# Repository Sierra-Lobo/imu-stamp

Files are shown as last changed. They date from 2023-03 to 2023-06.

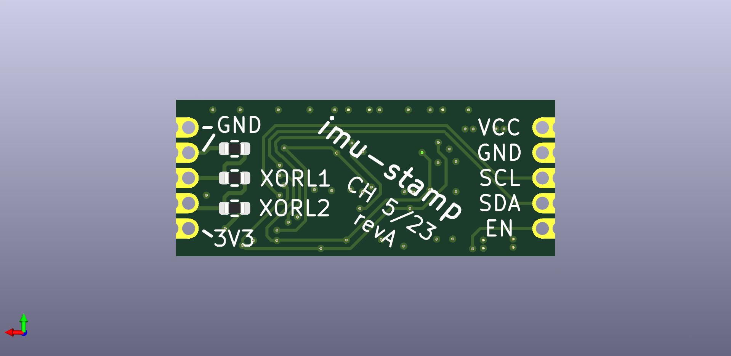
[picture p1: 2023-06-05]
hardware/revA/docs/imu-stamp-3d-bot.jpg

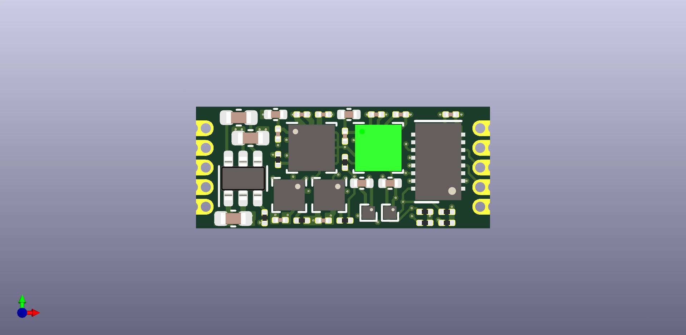
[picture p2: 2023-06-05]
hardware/revA/docs/imu-stamp-3d-top.jpg

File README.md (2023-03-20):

# imu-stamp

9-axis inertial measurement unit with dual sensors for gyro, mag, and accel measurements.

see LTC4317 datasheet for information on setting the I2C addresses of each sensor.

imu-stamp-3d-top

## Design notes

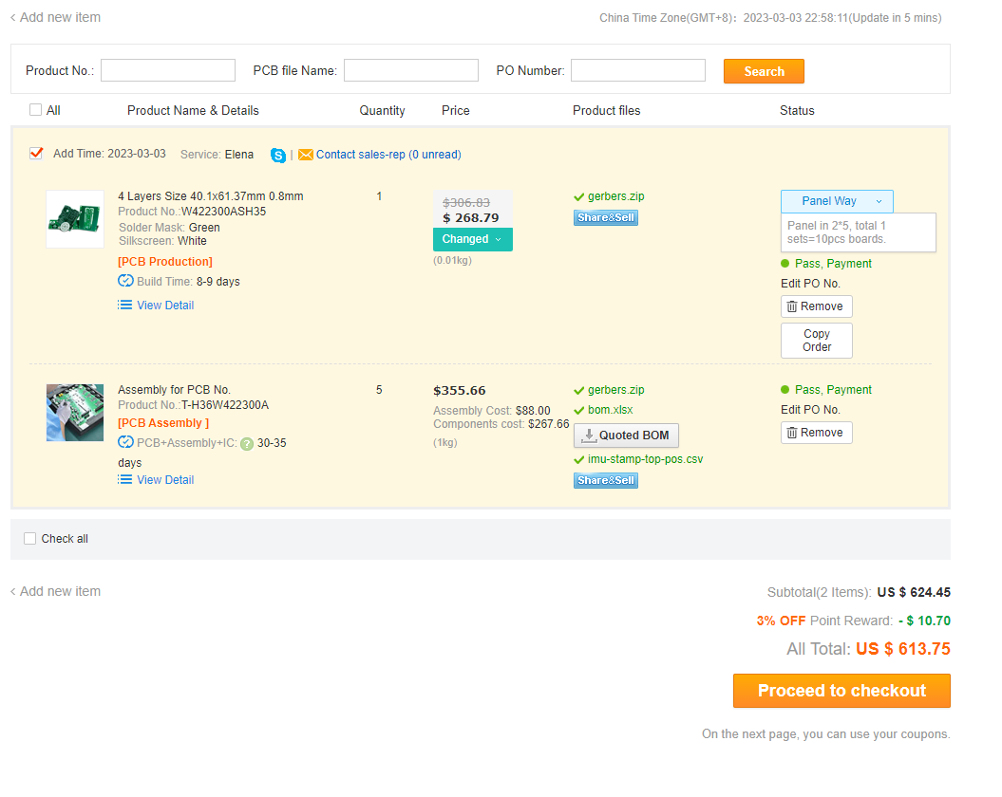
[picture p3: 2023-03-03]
hardware/revA/docs/PCBway-quote-230303.PNG

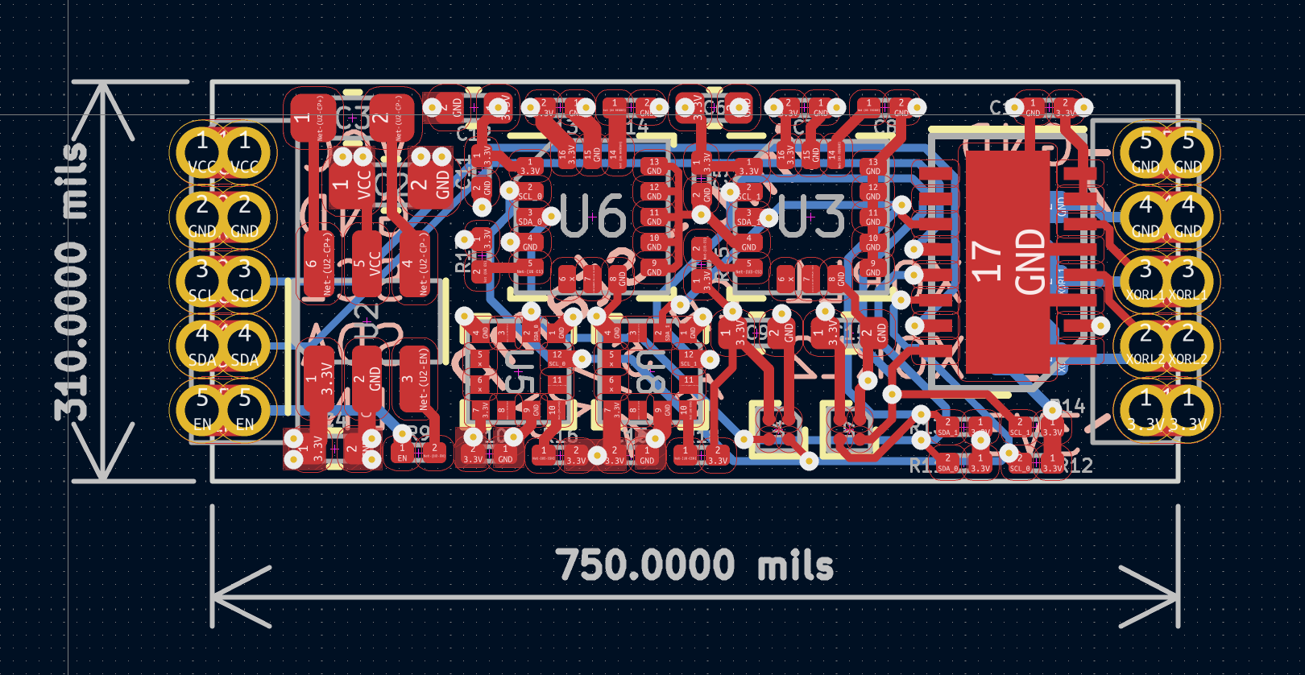
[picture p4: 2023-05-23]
hardware/revA/docs/imu-stamp-2d.PNG

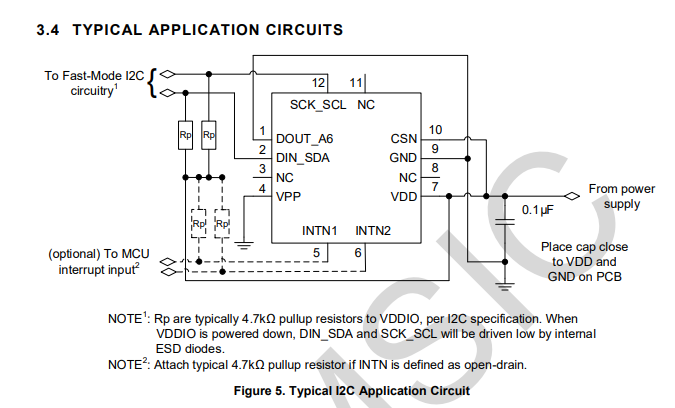
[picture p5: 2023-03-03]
design/mc3419-ref-ckt.PNG

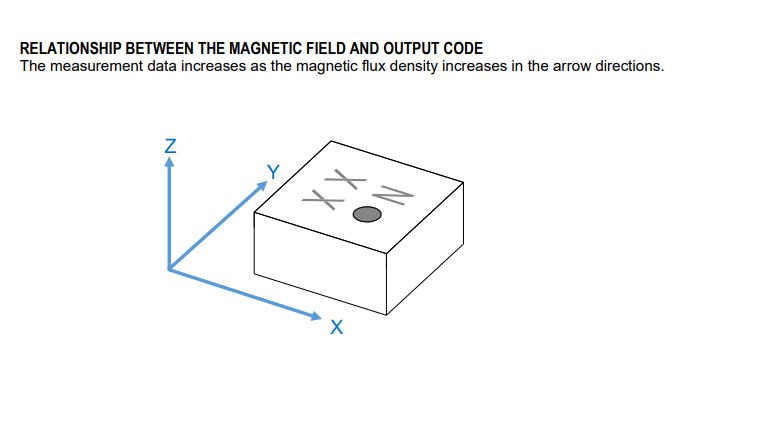
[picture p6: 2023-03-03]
design/MMC5603-orientation.PNG

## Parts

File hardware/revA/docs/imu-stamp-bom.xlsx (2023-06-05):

Component Count: | 33 | 5/32/23
Item | Qty | Reference(s) | Value | Footprint | Manufacturer | Manufacturer P/N
1 | 5 | C1, C7, C10, C13, C16 | 0.1uF | 0201 | Murata | GRT033R61A104KE01J
2 | 1 | C2 | 2.2uF | 0603 | TDK | CGA3E1X7R0J225K080AC
3 | 1 | C3 | 0.1uF | 0603 | TDK | CGA3E2X7R1H104K080AA
4 | 1 | C4 | 10uF | 0603 | TDK | CGA3E1X7T0J106M080AC
5 | 2 | C5, C11 | 10nF | 0201 | TDK | CGA1A2X7R0J103K030BA
6 | 4 | C6, C9, C12, C15 | 2.2uF | 0402 | Murata | GRT155C70J225KE13D
7 | 2 | C8, C14 | 0.47uF | 0201 | Murata | GRT033R60J474KE01D
8 | 5 | R9, R15, R16, R17, R18 | 10k | 0201 | Stackpole | RMCF0201FT10K0
9 | 4 | R11, R12, R13, R14 | 4.7k | 0201 | Stackpole | RMCF0201FT4K70
10 | 1 | U1 | LTC4317I | DFN-16-1EP_3x5mm_P0.5mm_EP1.66x4.4mm | Analog Devices | LTC4317IDHC
11 | 1 | U2 | REG710NA-3.3/3K | SOT-23-6 | Texas Instruments | REG710NA-3.3/3K
12 | 2 | U3, U6 | IAM-20380HT | LGA-16_3x3mm_P0.5mm | TDK | IAM-20380HT
13 | 2 | U4, U7 | MMC5603NJ | WLP-4_0.83x0.83mm_P0.4mm | Memsic | MMC5603NJ
14 | 2 | U5, U8 | MC3419 | LGA-12_2x2mm_P0.5mm | Memsic | MC3419

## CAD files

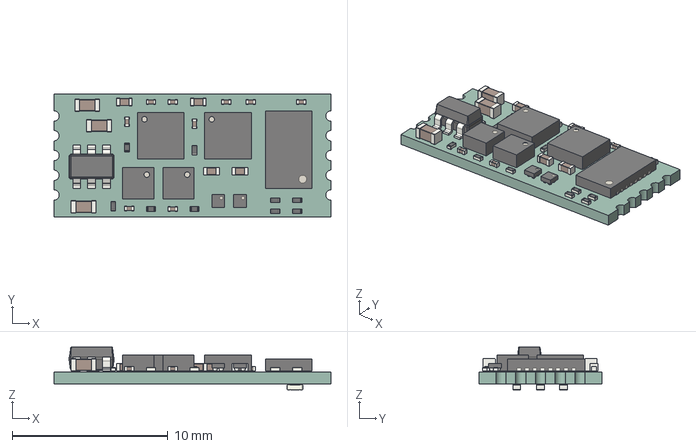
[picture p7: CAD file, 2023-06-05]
hardware/revA/docs/imu-stamp.step
17.8 x 7.87 x 2.76 mm
PCB

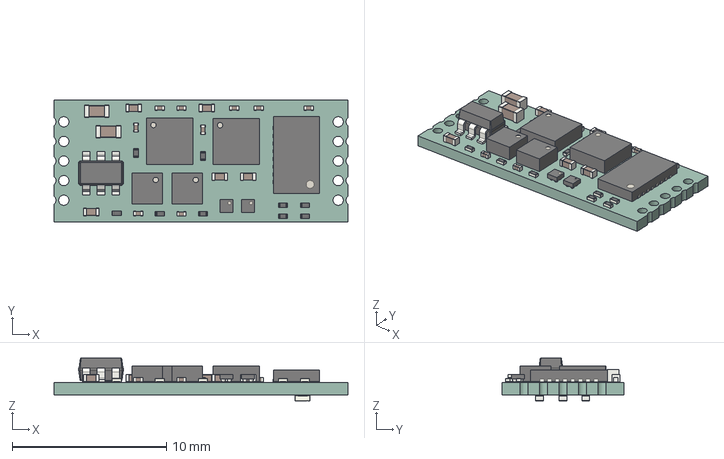
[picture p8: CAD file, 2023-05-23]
hardware/revA/imu-stamp.step
19.0 x 7.87 x 2.78 mm
PCB

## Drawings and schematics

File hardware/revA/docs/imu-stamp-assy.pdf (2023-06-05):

### No BOARD CHARACTERISTICS

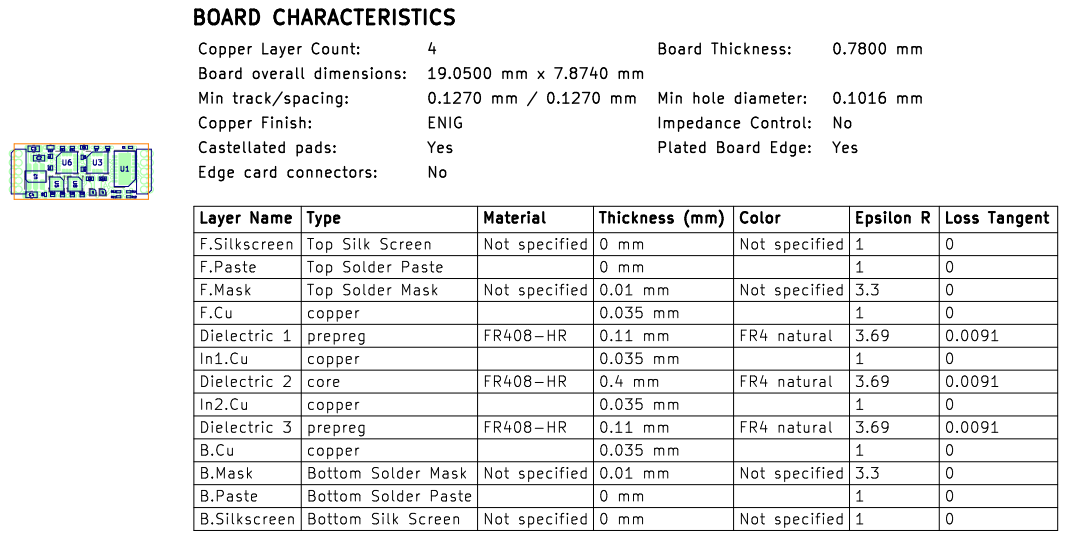
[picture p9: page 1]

Impedance | Control: FR408-HR

Not specified | Plated Board 0 mm | Color Edge: Yes B.Paste Not specified | | 0 F.Cu F.Mask 0.0091

copper Top Solder | | | Mask | | | FR4 natural FR408-HR | 3.69 Top Solder Paste | 0 No

copper | Thickness (mm) 0.035 mm | Not specified | 1 | 0 B.Silkscreen 0 B.Cu

Top Silk | Screen | | | 0 mm

In1.Cu | | Not specified F.Paste | | | | 1 Not specified | 0 Not specified 0.0091

0.01 mm 0.035 mm | | 1 FR4 natural Bottom Solder Mask

core | | 0.4 mm | | 3.3 FR4 natural | 0

prepreg B.Mask | | | | | 1 3.69
Dielectric 3 | Bottom Solder Paste | | 0.035 mm

copper | | 0.035 mm | | | 0

0 mm | | 1 Not specified

Id: 1/1 Title: File: imu-stamp.kicad_pcb Sheet:

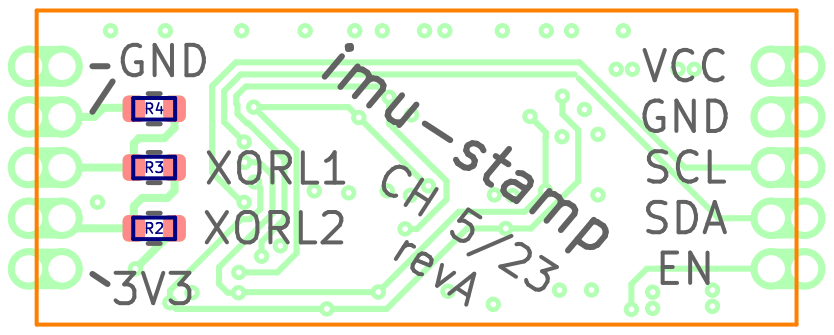
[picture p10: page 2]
D Date: KiCad; kicad; 7.0.1 Size: A4; Rev:

Id: 1/1 Title: File: imu-stamp.kicad_pcb Sheet:

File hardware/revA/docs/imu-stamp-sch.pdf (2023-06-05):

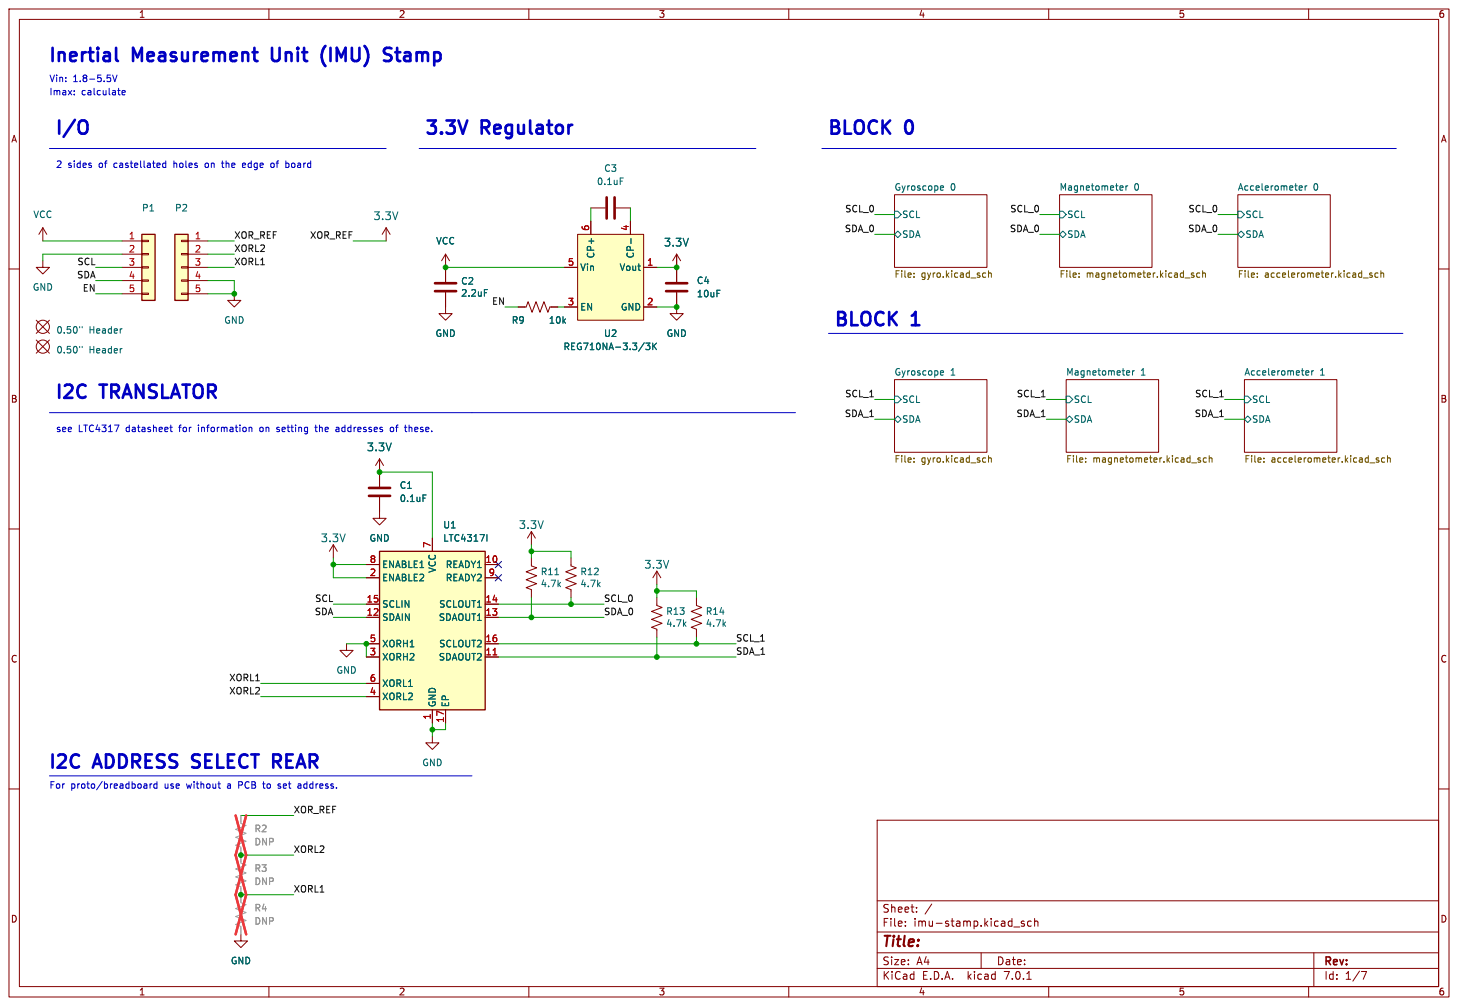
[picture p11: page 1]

Inertial Measurement Unit (IMU) Stamp

1 READY1 10 SDAOUT2 11 SDAIN 12 SDAOUT1 13 SCLOUT1 14 SCLIN 15 SCLOUT2 16 EP 17 ENABLE2 2 XORH2 3 XORL2 4 XORH1 5 XORL1 6 VCC

Id: 1/7 Title: File: imu-stamp.kicad_sch Sheet: /

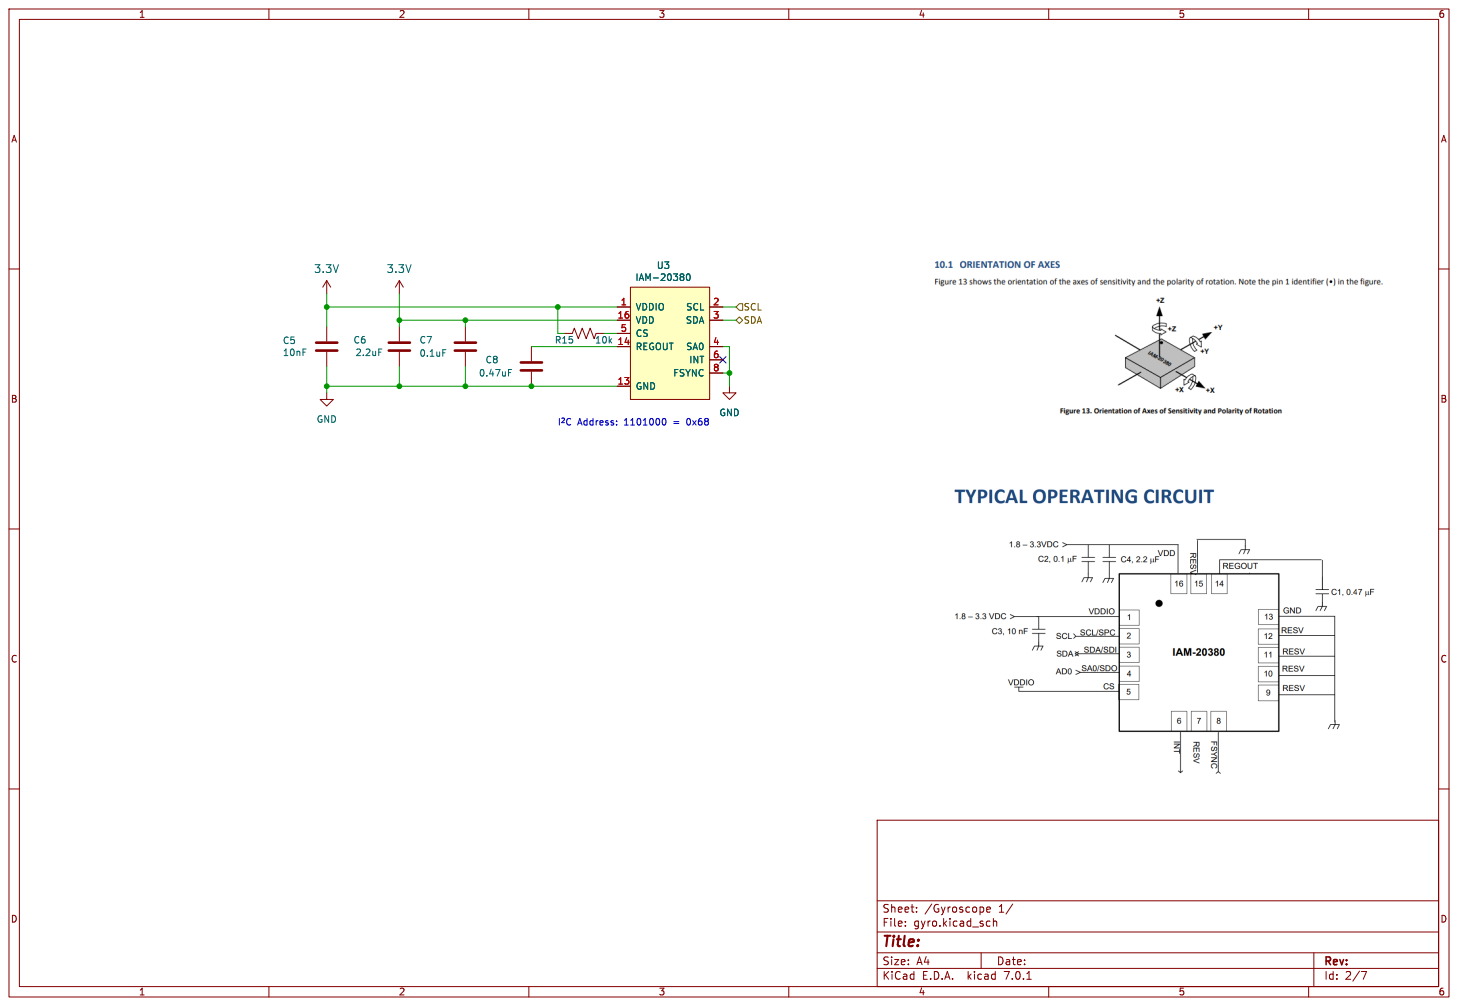
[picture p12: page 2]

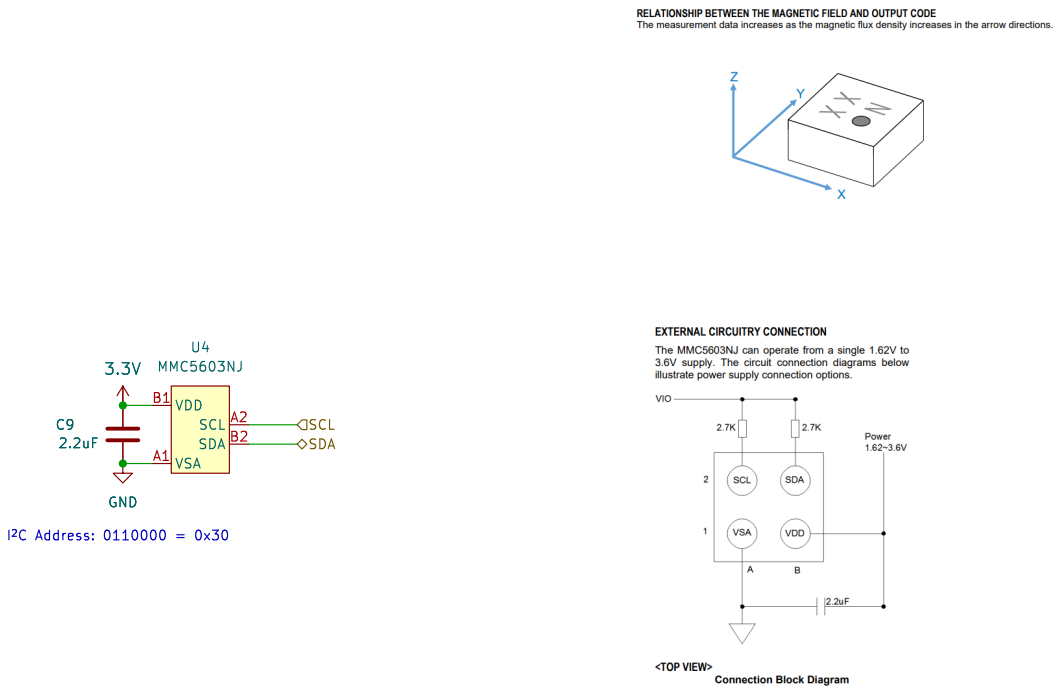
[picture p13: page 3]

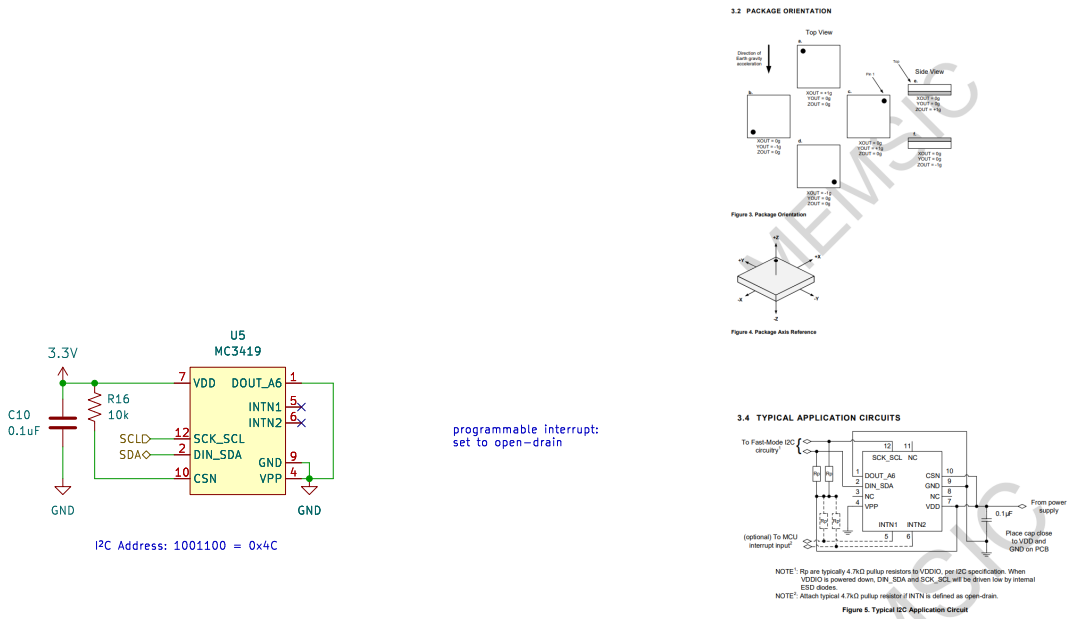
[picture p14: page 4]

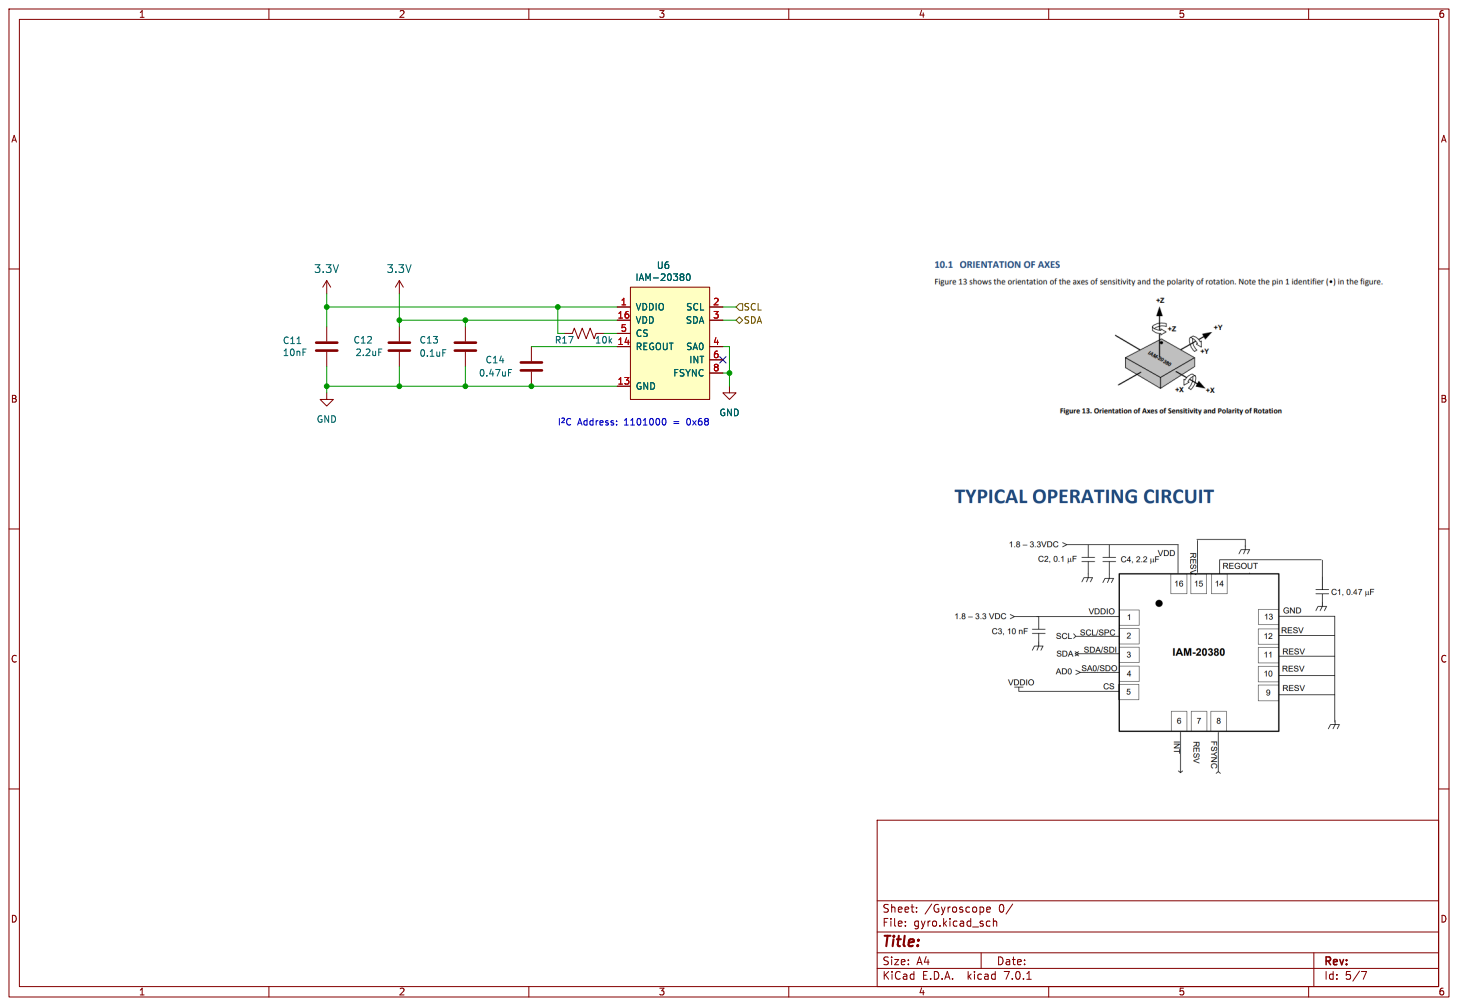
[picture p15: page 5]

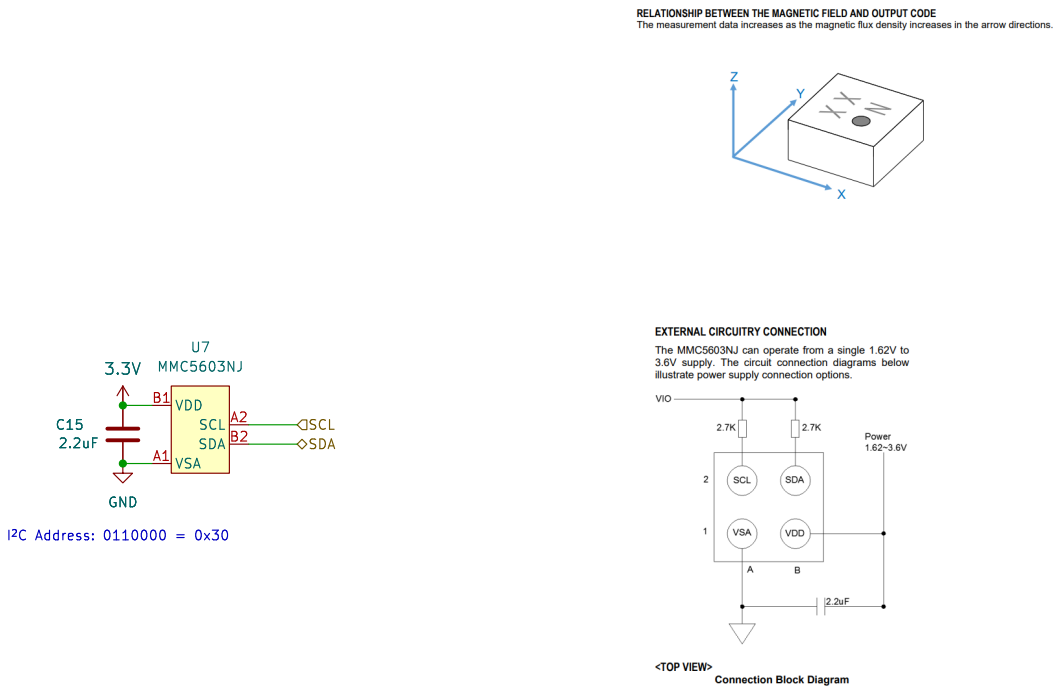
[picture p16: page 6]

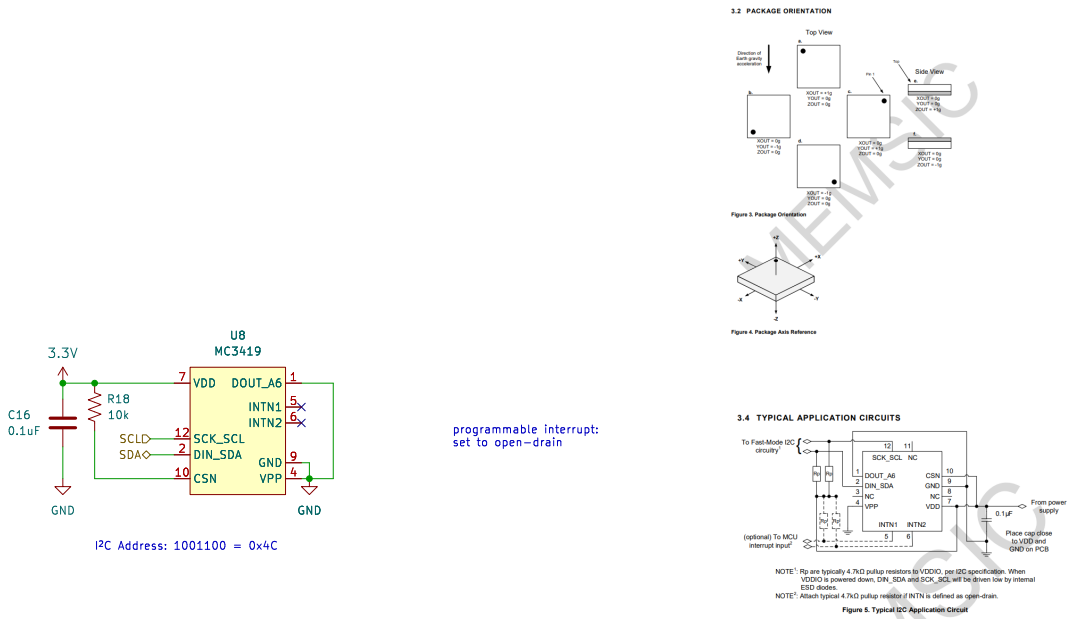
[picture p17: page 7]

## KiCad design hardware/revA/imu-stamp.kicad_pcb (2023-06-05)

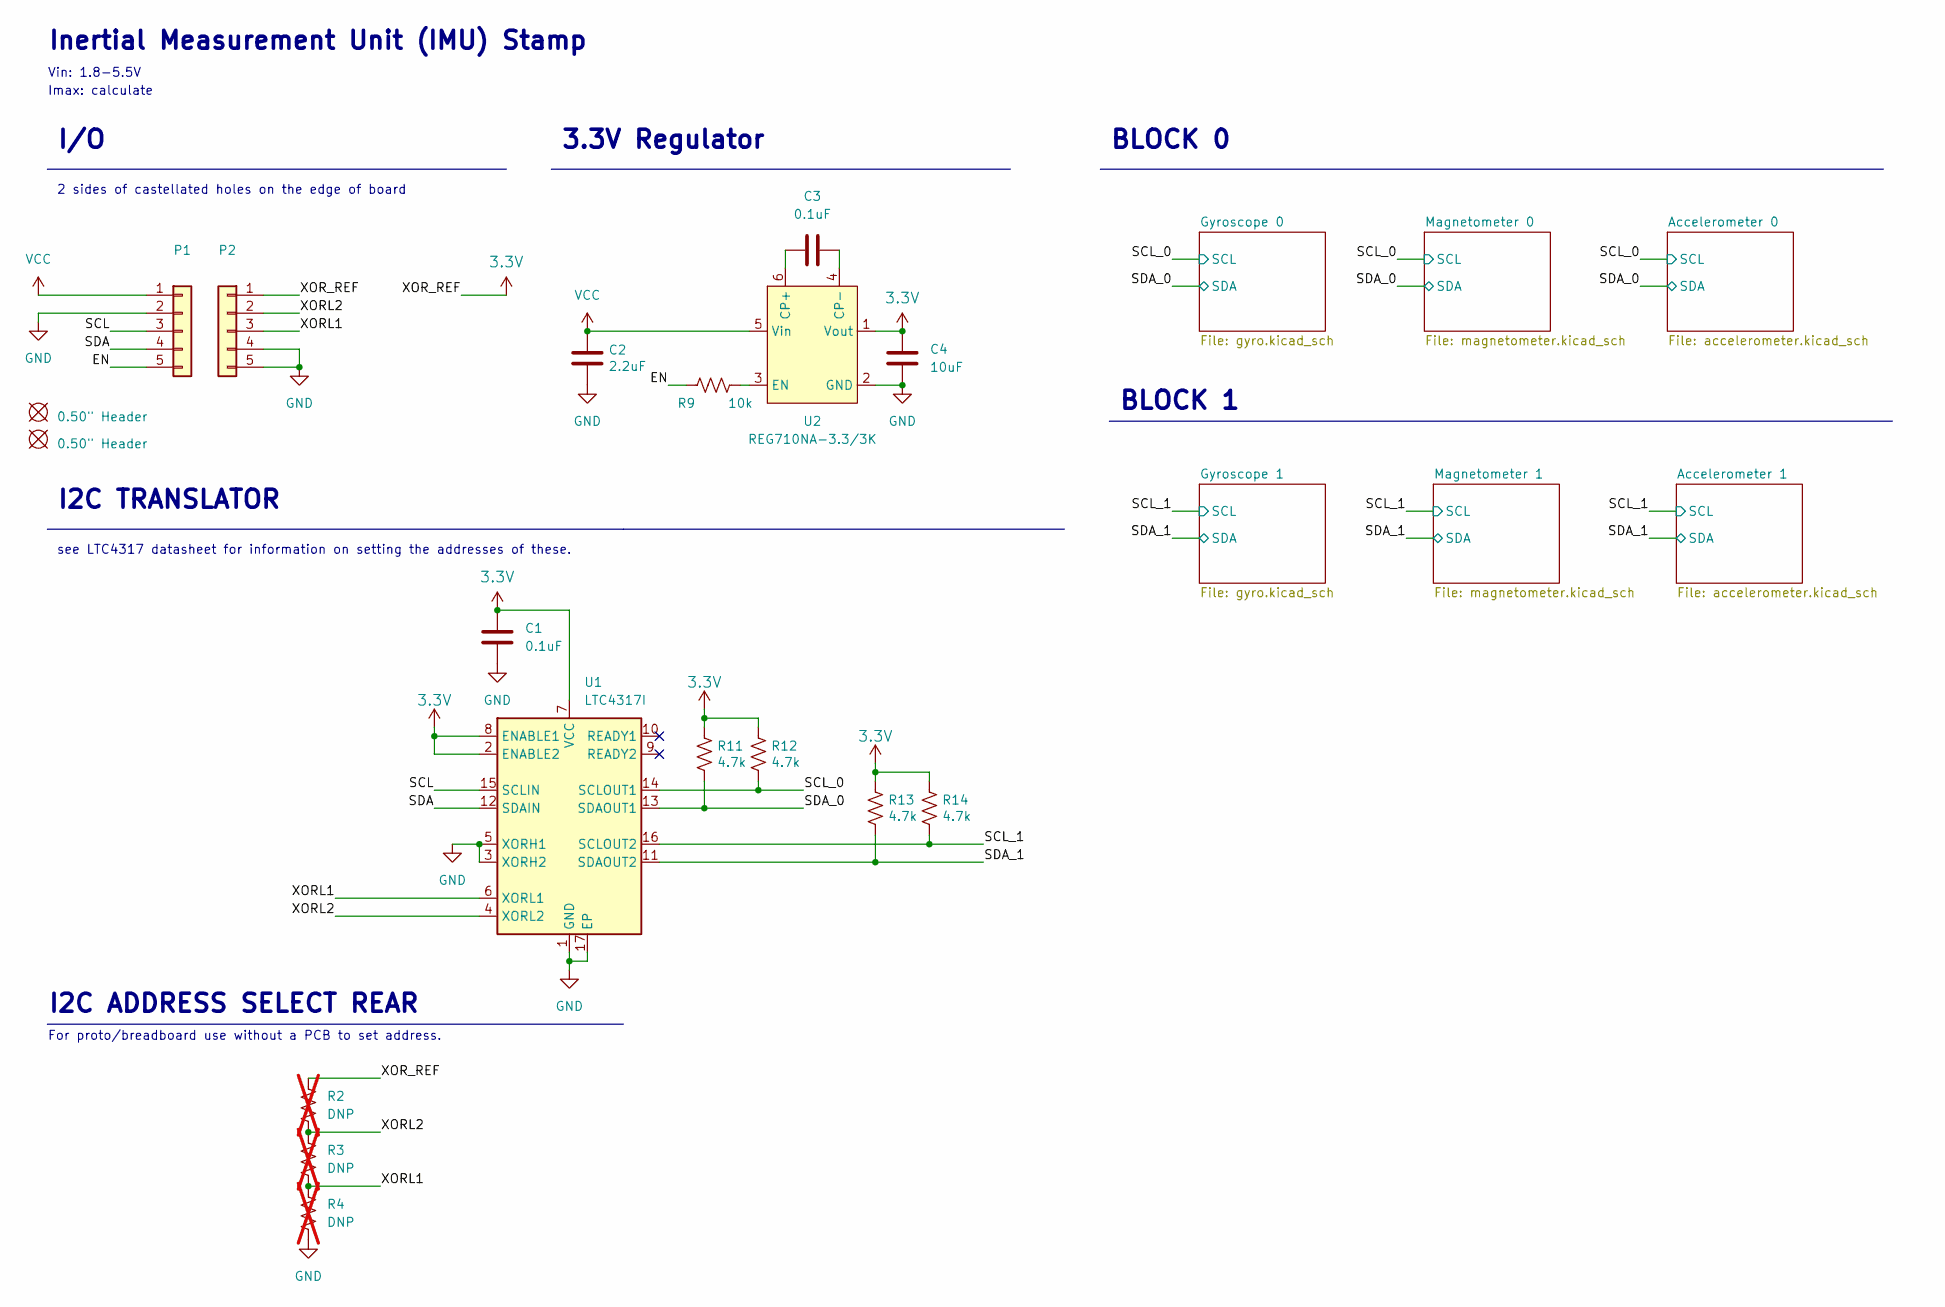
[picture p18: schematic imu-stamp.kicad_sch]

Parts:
BOM1, BOM2: 0.50" Header
C1: 0.1uF; C_0201_0603Metric
C2: 2.2uF; C_0603_1608Metric
C3: 0.1uF; C_0603_1608Metric
C4: 10uF; C_0603_1608Metric
P1, P2: I/O; Castellated_1x05_P1.27mm_Vertical
R2, R3, R4: DNP; R_0402_1005Metric; not fitted
R9: 10k; R_0201_0603Metric
R11, R12, R13, R14: 4.7k; R_0201_0603Metric
U1: LTC4317I; DFN-16-1EP_3x5mm_P0.5mm_EP1.66x4.4mm
U2: REG710NA-3.3/3K; SOT-23-6

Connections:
3.3V: C1.2, C4.1, P2.1, R2.1, R11.1, R12.1, R13.1, R14.1, U1.2 (ENABLE2), U1.7 (VCC), U1.8 (ENABLE1), U2.1 (Vout); also elsewhere on the board
/EN: P1.5, R9.1
/SCL: P1.3, U1.15 (SCLIN)
/SCL_0: R12.2, U1.14 (SCLOUT1); also elsewhere on the board
/SCL_1: R14.2, U1.16 (SCLOUT2); also elsewhere on the board
/SDA: P1.4, U1.12 (SDAIN)
/SDA_0: R11.2, U1.13 (SDAOUT1); also elsewhere on the board
/SDA_1: R13.2, U1.11 (SDAOUT2); also elsewhere on the board
/XORL1: P2.3, R3.2, R4.1, U1.6 (XORL1)
/XORL2: P2.2, R2.2, R3.1, U1.4 (XORL2)
GND: C1.1, C2.2, C4.2, P1.2, P2.4, P2.5, R4.2, U1.1 (GND), U1.3 (XORH2), U1.5 (XORH1), U1.17 (EP), U2.2 (GND); also elsewhere on the board
unnamed: C3.1, U2.6 (CP+)
unnamed: C3.2, U2.4 (CP-)
unnamed: R9.2, U2.3 (EN)
VCC: C2.1, P1.1, U2.5 (Vin)

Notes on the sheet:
I2C TRANSLATOR
2 sides of castellated holes on the edge of board
Imax: calculate
I/O
see LTC4317 datasheet for information on setting the addresses of these.
Inertial Measurement Unit (IMU) Stamp
I2C ADDRESS SELECT REAR
BLOCK 0
BLOCK 1
Vin: 1.8-5.5V
For proto/breadboard use without a PCB to set address.
3.3V Regulator

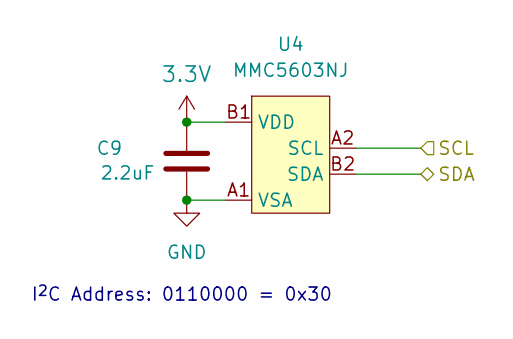
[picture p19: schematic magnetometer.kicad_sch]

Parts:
C9: 2.2uF; C_0402_1005Metric
U4: MMC5603NJ; WLP-4_0.83x0.83mm_P0.4mm

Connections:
3.3V: C9.1, U4.B1 (VDD); also elsewhere on the board
/SCL_0: U4.A2 (SCL); also elsewhere on the board
/SDA_0: U4.B2 (SDA); also elsewhere on the board
GND: C9.2, U4.A1 (VSA); also elsewhere on the board

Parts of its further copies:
C15: 2.2uF; C_0402_1005Metric
U7: MMC5603NJ; WLP-4_0.83x0.83mm_P0.4mm

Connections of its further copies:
3.3V: C15.1, U7.B1 (VDD); also elsewhere on the board
/SCL_1: U7.A2 (SCL); also elsewhere on the board
/SDA_1: U7.B2 (SDA); also elsewhere on the board
GND: C15.2, U7.A1 (VSA); also elsewhere on the board

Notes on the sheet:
I^{2}C Address: 0110000 = 0x30

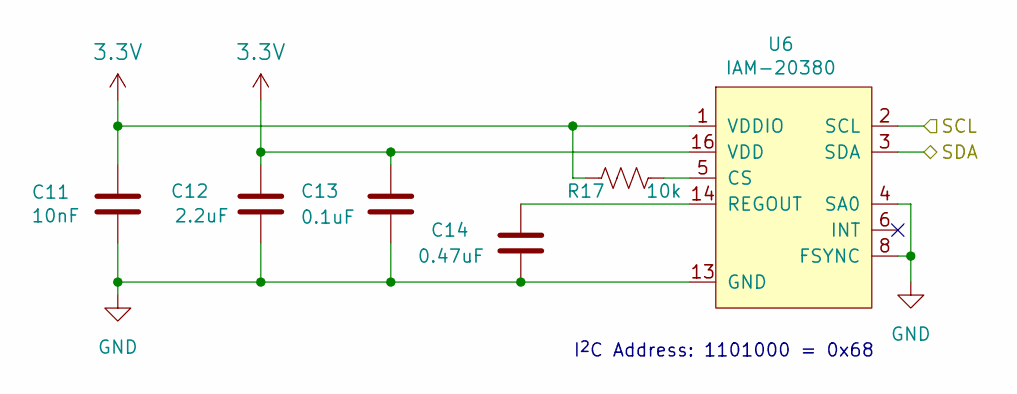
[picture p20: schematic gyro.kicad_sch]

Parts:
C11: 10nF; C_0201_0603Metric
C12: 2.2uF; C_0402_1005Metric
C13: 0.1uF; C_0201_0603Metric
C14: 0.47uF; C_0201_0603Metric
R17: 10k; R_0201_0603Metric
U6: IAM-20380; LGA-16_3x3mm_P0.5mm_LayoutBorder3x5y

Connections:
3.3V: C11.1, C12.1, C13.2, R17.1, U6.1 (VDDIO), U6.16 (VDD); also elsewhere on the board
/SCL_0: U6.2 (SCL); also elsewhere on the board
/SDA_0: U6.3 (SDA); also elsewhere on the board
GND: C11.2, C12.2, C13.1, C14.2, U6.4 (SA0), U6.8 (FSYNC), U6.9 (RESV_GND), U6.10 (RESV_GND), U6.11 (RESV_GND), U6.12 (RESV_GND), U6.13 (GND), U6.15 (RESV_GND); also elsewhere on the board
unnamed: R17.2, U6.5 (CS)
unnamed: C14.1, U6.14 (REGOUT)

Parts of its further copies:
C5: 10nF; C_0201_0603Metric
C6: 2.2uF; C_0402_1005Metric
C7: 0.1uF; C_0201_0603Metric
C8: 0.47uF; C_0201_0603Metric
R15: 10k; R_0201_0603Metric
U3: IAM-20380; LGA-16_3x3mm_P0.5mm_LayoutBorder3x5y

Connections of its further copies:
3.3V: C5.1, C6.1, C7.2, R15.1, U3.1 (VDDIO), U3.16 (VDD); also elsewhere on the board
/SCL_1: U3.2 (SCL); also elsewhere on the board
/SDA_1: U3.3 (SDA); also elsewhere on the board
GND: C5.2, C6.2, C7.1, C8.2, U3.4 (SA0), U3.8 (FSYNC), U3.9 (RESV_GND), U3.10 (RESV_GND), U3.11 (RESV_GND), U3.12 (RESV_GND), U3.13 (GND), U3.15 (RESV_GND); also elsewhere on the board
unnamed: R15.2, U3.5 (CS)
unnamed: C8.1, U3.14 (REGOUT)

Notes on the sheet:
I^{2}C Address: 1101000 = 0x68

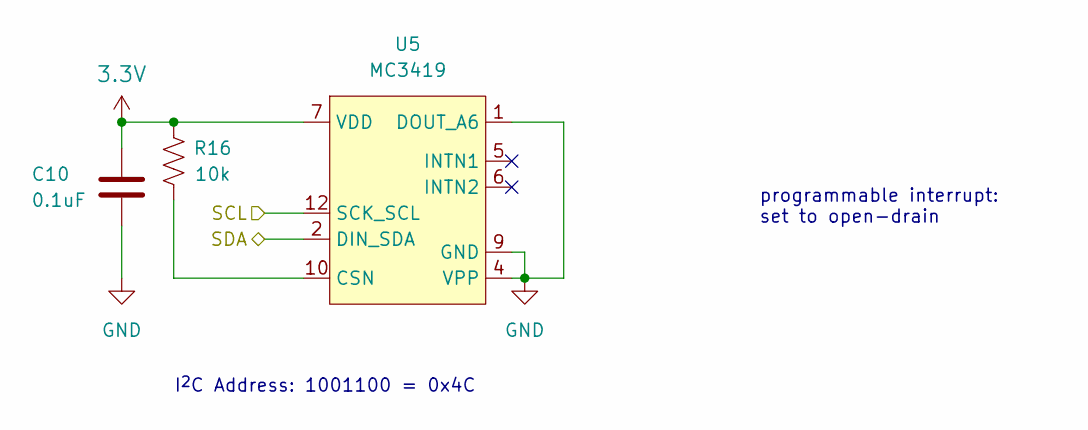
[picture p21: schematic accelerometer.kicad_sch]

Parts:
C10: 0.1uF; C_0201_0603Metric
R16: 10k; R_0201_0603Metric
U5: MC3419; LGA-12_2x2mm_P0.5mm

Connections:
3.3V: C10.2, R16.2, U5.7 (VDD); also elsewhere on the board
/SCL_0: U5.12 (SCK_SCL); also elsewhere on the board
/SDA_0: U5.2 (DIN_SDA); also elsewhere on the board
GND: C10.1, U5.1 (DOUT_A6), U5.4 (VPP), U5.9 (GND); also elsewhere on the board
unnamed: R16.1, U5.10 (CSN)

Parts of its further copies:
C16: 0.1uF; C_0201_0603Metric
R18: 10k; R_0201_0603Metric
U8: MC3419; LGA-12_2x2mm_P0.5mm

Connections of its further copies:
3.3V: C16.2, R18.2, U8.7 (VDD); also elsewhere on the board
/SCL_1: U8.12 (SCK_SCL); also elsewhere on the board
/SDA_1: U8.2 (DIN_SDA); also elsewhere on the board
GND: C16.1, U8.1 (DOUT_A6), U8.4 (VPP), U8.9 (GND); also elsewhere on the board
unnamed: R18.1, U8.10 (CSN)

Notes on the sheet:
I^{2}C Address: 1001100 = 0x4C
programmable interrupt: set to open-drain

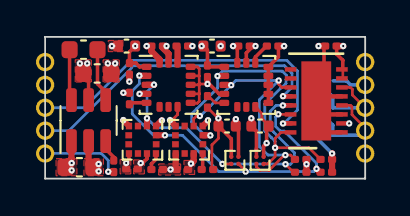
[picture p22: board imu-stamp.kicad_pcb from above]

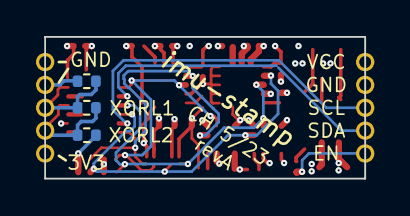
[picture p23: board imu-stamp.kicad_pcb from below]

Board: 4 copper layers, 17.8 x 7.9 mm, 38 parts (3 on the bottom side), 21 nets.

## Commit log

2023-03-07 updated iam20380 footprint
    to exclude solder mask per AN-IVS-0002A-00
    [imu-stamp-B_Cu.gbr, imu-stamp-B_Mask.gbr, imu-stamp-B_Paste.gbr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]
2023-03-14 adjusted castellated hole size and position
    [bom.xlsx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]
2023-03-22 moved software to a different repo
    [addresses.xlsx]
2023-05-23 consistency updates
    [accelerometer.kicad_sch, bom.xlsx, gyro.kicad_sch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]
2023-06-05 resized board for manufacturing
    [bom.xlsx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]
